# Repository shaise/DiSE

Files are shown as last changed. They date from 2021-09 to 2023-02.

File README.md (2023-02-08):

# DiSE
A DIY speed editor to use with video editing sw such as Davinci Resolve and others  
  
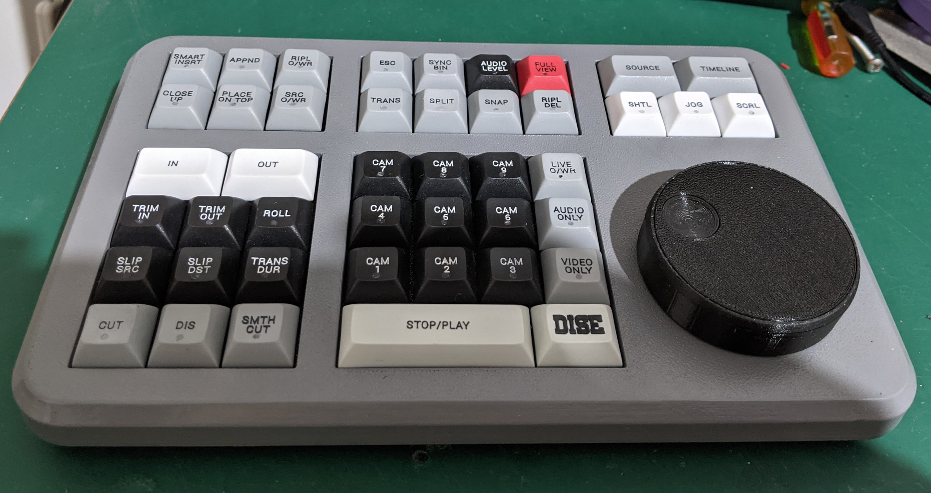
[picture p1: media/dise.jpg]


## Bill Of Materials:
- 1 [Bluepill Processor Board](#processor-module) 
- 1 [100ppr 5v Encoder](#encoder) 
- 44 [Cherry MX Keys and Sockets](#cherry-keys)
- 44 [Different sized Key Caps](#key-caps)
    -  DSA22 1u 18pc (18 x 1u)  
    -  DSA17 1u 18pc (18 x 1u)  
    -  DSA19 1u 4pc (4 x 1u)  
    -  DSA1 1u 3pc (3 x 1u)  
    -  DSA22 1.5u 2pc (4 x 1u)  
    -  DSA19 1.5u 2pc (4 x 1u)  
    -  DSA21 2u 2pc (4 x 1u)  
    -  DSA21 1.25u 1pc (2 x 1u)  
    -  DSA21 2.75u 1pc (3 x 1u)  
- 44 [3mm LEDs](#leds)  
- 1 [USB-C Connector](#usbc-connector)
- 18 [0603 Resistors (2x1k, 7x330R, 7x68R)](#resistors)
- 1 [small schottky diode](#diode)
- (Optional) [Encoder Connector](#connector)
- Access to a 3d Printer to print the case and knob under the mechanics folder.

### Processor Module:
Beware there are out there many STM32103 Clones under the blue pill name. Some Clones may not perform as the original STM32 processor. [More info](https://hackaday.com/2020/10/22/stm32-clones-the-good-the-bad-and-the-ugly/).
Definitely STM Software Utillities try hard to identify their own branded original chipsets and wont work on any other detectable clone. Wich makes debugging and developping very difficult.

#### **Recommended** 
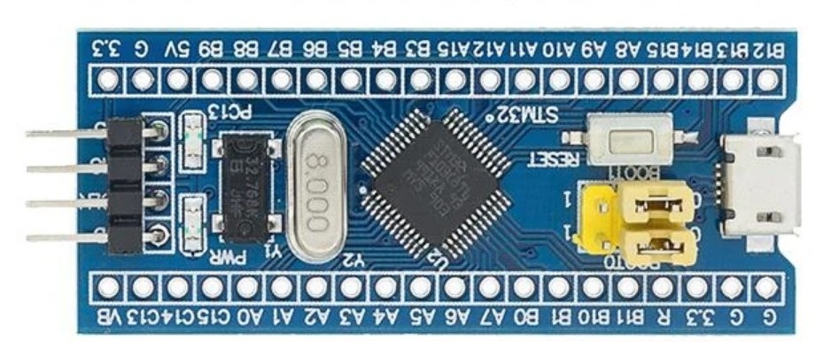
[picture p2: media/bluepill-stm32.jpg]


Blue-Pill with original STM32 Processor module: https://www.aliexpress.com/item/1766455290.html 
(order both STM32F103C8T6 and ST-Link V2 programmer)

#### **Cheaper Alternative** 
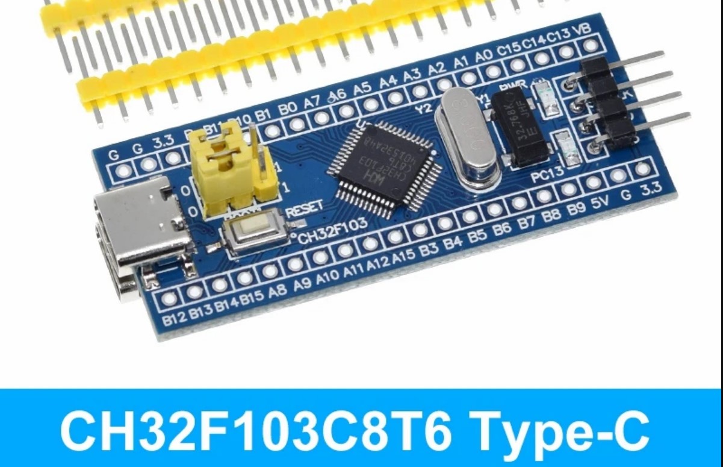
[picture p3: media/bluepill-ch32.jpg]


Blue-Pill with CH32F103C8T6 and two usb Ports. No need of ST-Link programmer. One USB-C port is used to download/upgrade the firmware using wch programming software. Can also be programmed with an ST-Link dongle and the old ST-Link004 from STM.
(Proved to work, cheaper, not compatible with newer STM Tools thought, only 64k, so not recomended for developping )

### Encoder
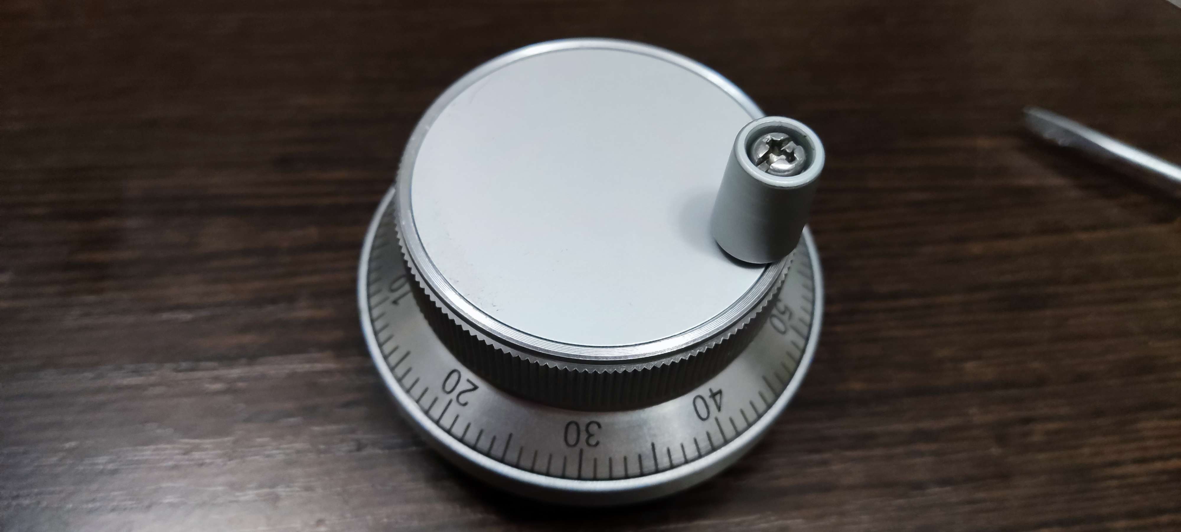
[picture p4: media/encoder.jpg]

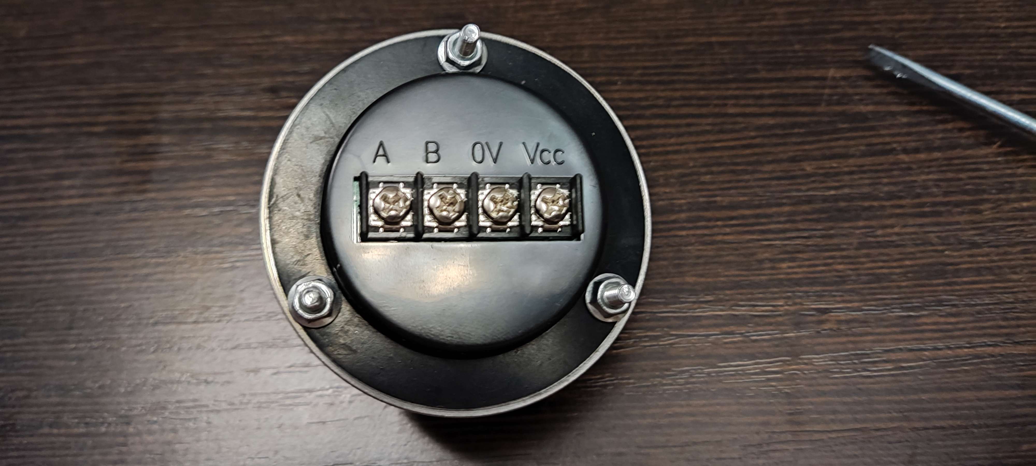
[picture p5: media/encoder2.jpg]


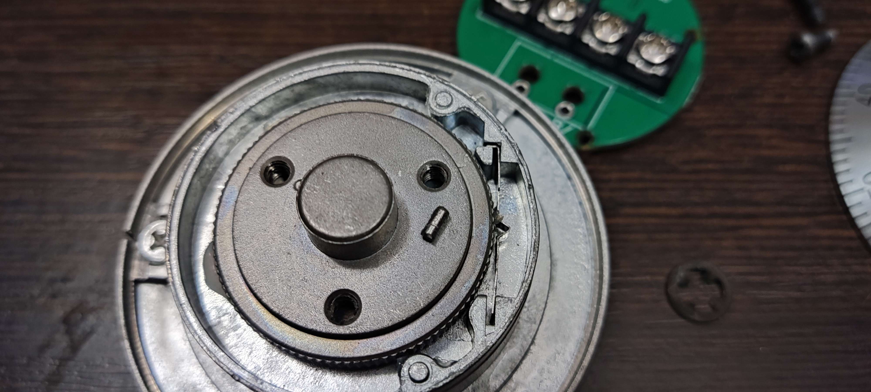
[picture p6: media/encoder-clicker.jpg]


**Optical Encoder 100ppr 5v 4pin 60mm** 
We will be modifying the top part to remove the bearing pin that acts as a clicker to let it run quieter and smoothly. 
The pin can be reached by removing the spindle handler screw, then remove the upper plate that it is glued to uncover the three screws that holds the knob in place, and after removing it dissasemble the support plate that holds the spring in place.
The pin can be taken from its place and saved safely for any future reassembly in the little space behind the spring.

Encoder: https://www.aliexpress.com/item/4000897699294.html 1 unit  

### Cherry Keys
Cherry MX Keys and Sockets

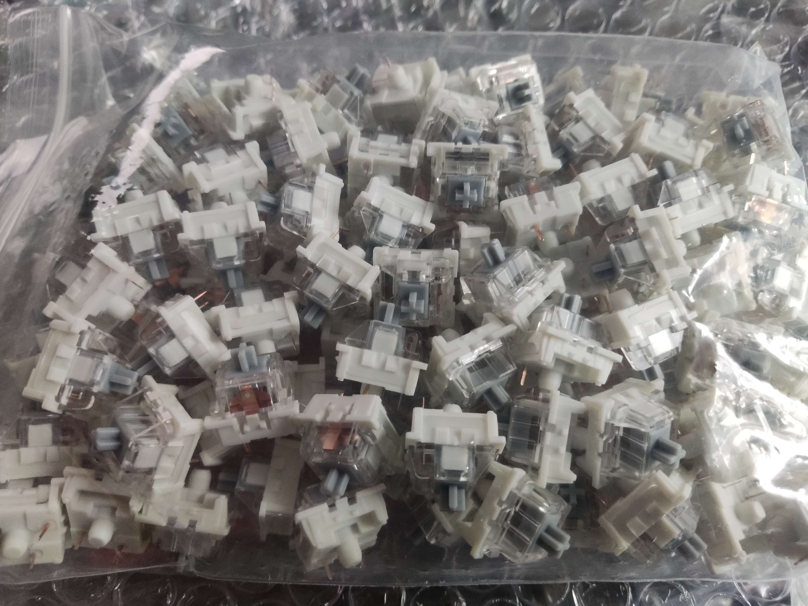
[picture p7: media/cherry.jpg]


Keys: https://www.aliexpress.com/item/1005002378701948.html Order Silent Gray type 44pcs (order 2 packs of 30)  

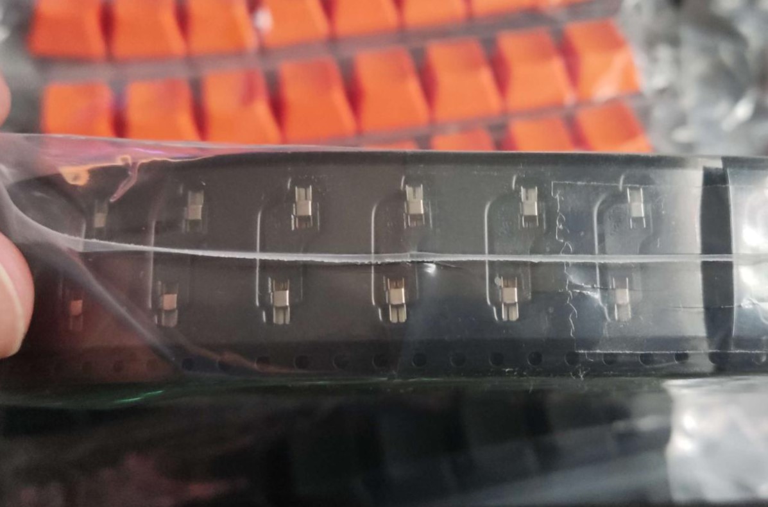
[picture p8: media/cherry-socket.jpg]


Key Sockets: https://www.aliexpress.com/item/4001051840976.html 44pcs (order 50 pcs ) 

### Key Caps
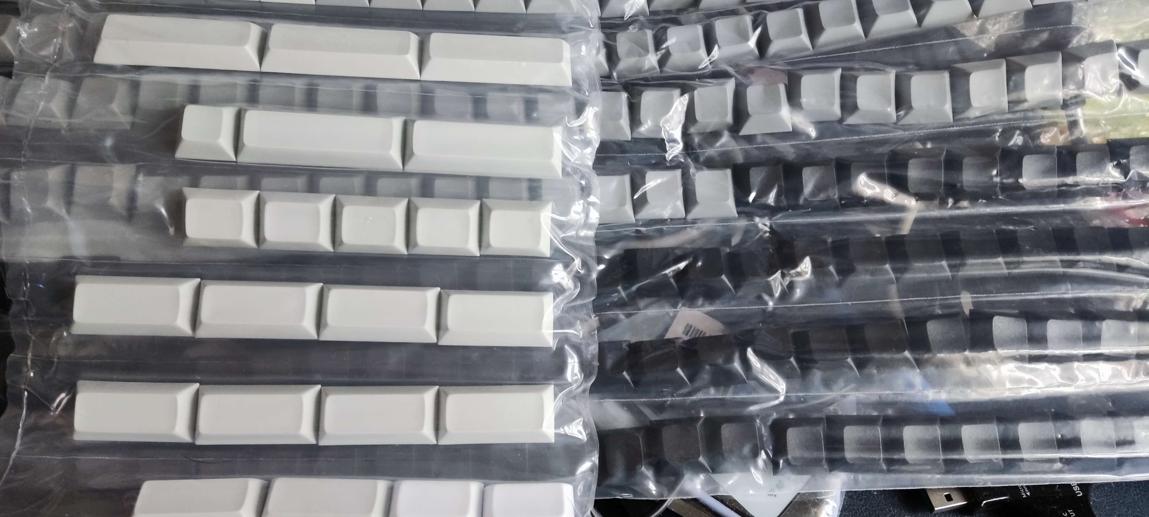
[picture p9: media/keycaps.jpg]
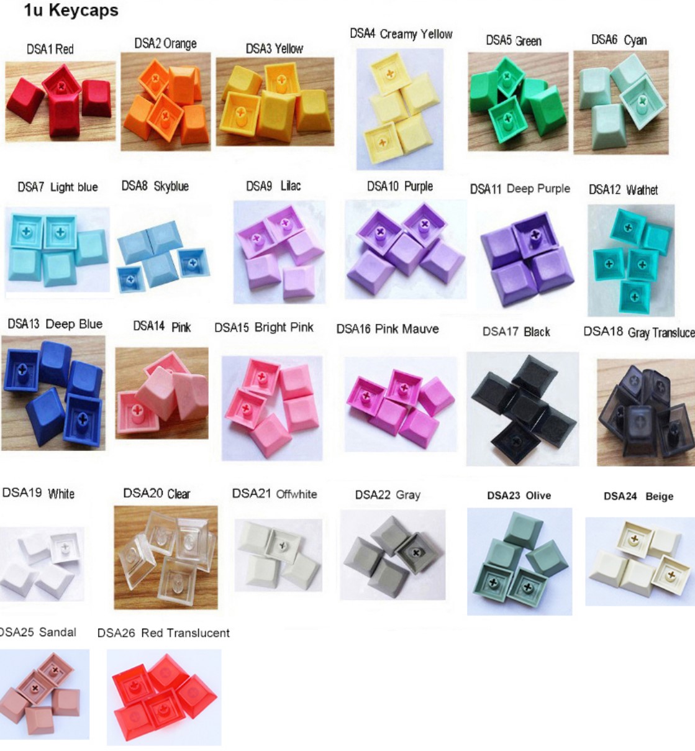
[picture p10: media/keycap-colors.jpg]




Key Caps: https://www.aliexpress.com/item/32850729893.html 44pcs (Order 60 pcs, and send the list below):  
-  DSA22 1u 18pc (18 x 1u)  (Gray)
-  DSA17 1u 18pc (18 x 1u)  (Black)
-  DSA19 1u 4pc (4 x 1u)    (White)
-  DSA1 1u 3pc (3 x 1u)     (Red)
-  DSA22 1.5u 2pc (4 x 1u)  (Gray)
-  DSA19 1.5u 2pc (4 x 1u)  (White)
-  DSA21 2u 2pc (4 x 1u)    (OffWhite)
-  DSA21 1.25u 1pc (2 x 1u) (OffWhite)
-  DSA21 2.75u 1pc (3 x 1u) (OffWhite)

This list will match the colors shown on the example picture showed above. 
Printing the layout text on the keycaps can be done using thermal sublimation ink, or laser printed.

**Beware** that if you don't have access to a printer with white thermal sublimation ink printing on the black keycaps (DSA17) can be challenging. You may want to change those to another color from the upper color table so you can transfer your layout text using common black toner for laser printers, or dark transfer ink.

Those samples were printed using whiteboard markers and a L1 laserpecker:

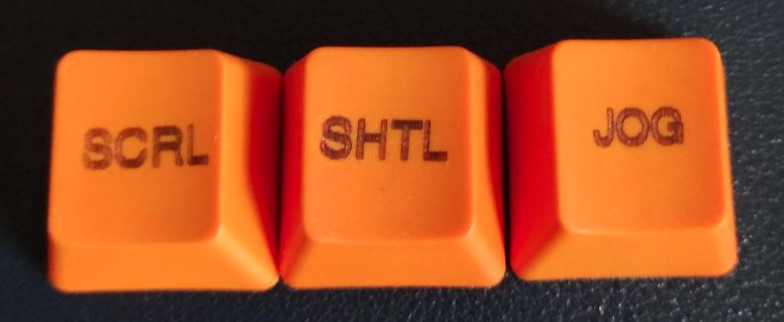
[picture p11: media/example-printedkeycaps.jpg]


This sample was lasered with a laserpecker and then filled the gap with paint. (extremely difficult to get it right)

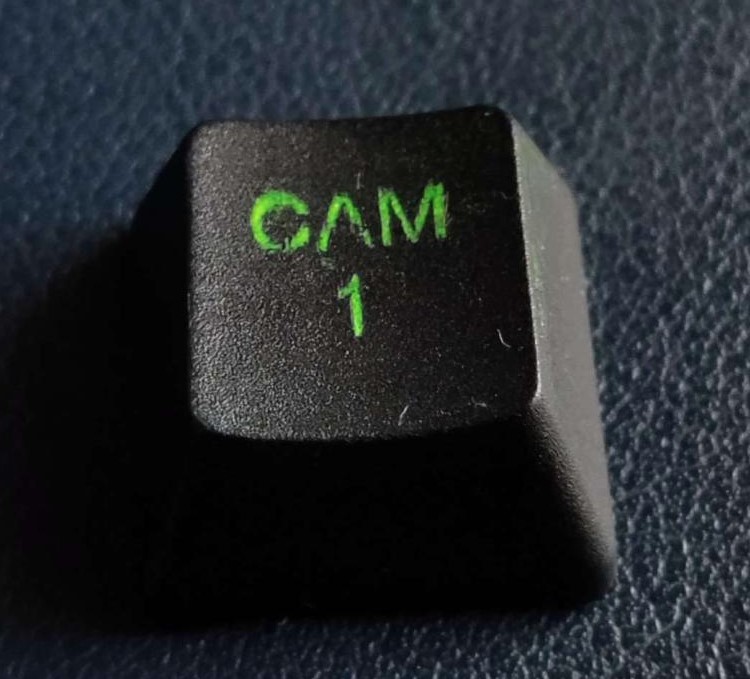
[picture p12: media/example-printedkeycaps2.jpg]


Check the assembly instructions to know more about how to DIY the keycap printing.

### LEDs 
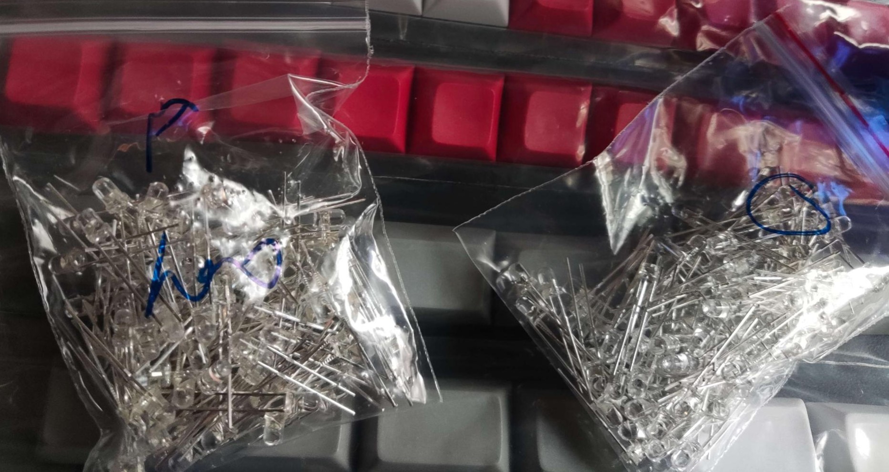
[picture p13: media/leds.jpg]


Standard 3mm LEDs. Any color. 
https://www.aliexpress.com/item/32685518028.html or any 3mm led, any color  44pcs

### USBC Connector
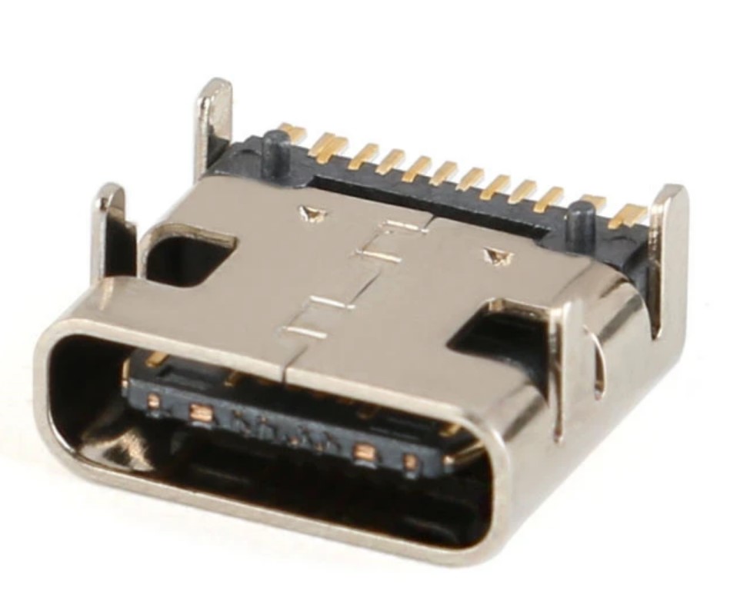
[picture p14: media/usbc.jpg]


If you chose the path of using the CH32 board, there is already a working connector you can use. Should that be the case, usbc cable can be plugged from right side. This breaked out connector is to move that to the center top.
If you chose the bluepill with only one usb connector (micro USB) there is no way around soldering this connector.

USB C connector: https://www.aliexpress.com/item/32976750426.html  

### Resistors 
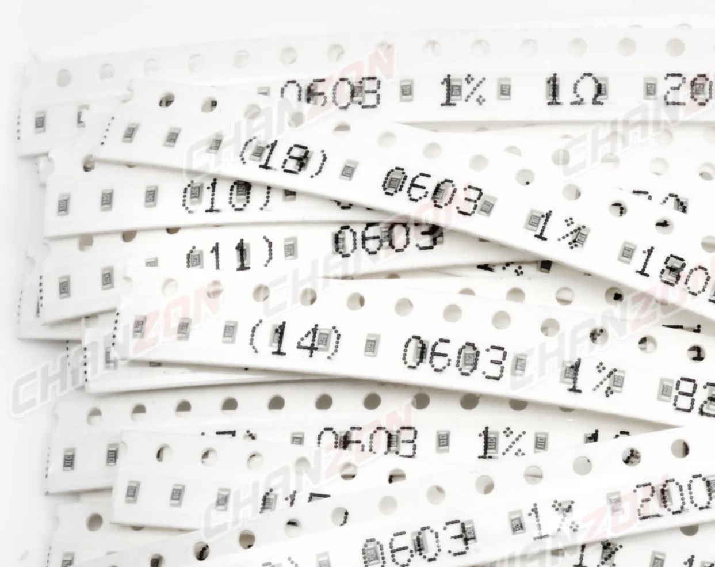
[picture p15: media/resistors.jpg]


0603 resistor kit: https://www.aliexpress.com/item/1005002364437129.html . Usage:
- R1 - R7 : 330 ohm (7pcs)
- R10 - R11 : 22 ohm (2pcs)
- R8 - R9 : 1K ohm (2pcs)
- R43 - R51: 68 ohm (7pcs)

If you struggle to find a kit that has the 68ohm value, 62ohm will work as well.

### Diode
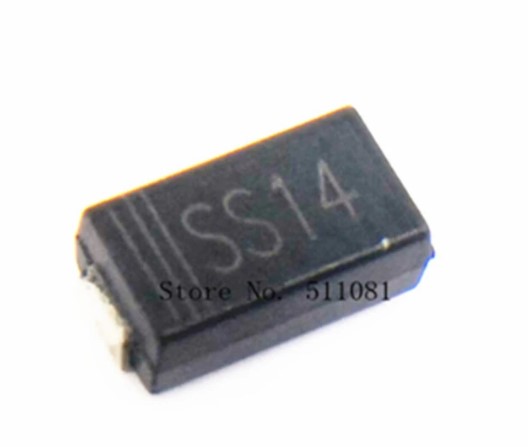
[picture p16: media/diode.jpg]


A small schottky diode. A 1N5819 SS14 SMD will work. 
1pc Needed, But its cheaper to get 100 than only one. https://www.aliexpress.com/item/627622453.html

### Connector
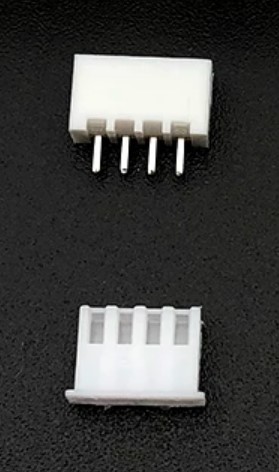
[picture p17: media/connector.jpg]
 

Optional 4pin pcb connector for the encoder. You may just skip this and solder the wires direct to the pcb

https://www.aliexpress.com/item/4000126563819.html

### Instructions 
TBD

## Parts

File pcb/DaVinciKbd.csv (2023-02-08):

Source: | C:\Users\carlo\Documents\GitHub\DiSE\pcb\DaVinciKbd.kicad_sch
Date: | 04/02/2023 15:40:26
Tool: | Eeschema (6.0.7)
Generator: | C:\Program Files\KiCad\6.0\bin\scripting\plugins/bom_csv_grouped_by_value.py
Component Count: | 79
Individual Components:
Item | Qty | Reference(s) | Value | LibPart | Footprint | Datasheet
 |  | D1 | 1N5819 | Device:D_Schottky_Small | Diode_SMD:D_SMA | ~
 |  | H1 | 3.6 MountingHole | Mechanical:MountingHole | BP:MountHole3.6 | ~
 |  | H2 | 3.6 MountingHole | Mechanical:MountingHole | BP:MountHole3.6 | ~
 |  | H3 | 3.6 MountingHole | Mechanical:MountingHole | BP:MountHole3.6 | ~
 |  | H4 | 3.6 MountingHole | Mechanical:MountingHole | BP:MountHole3.6 | ~
 |  | H5 | 3.6 MountingHole | Mechanical:MountingHole | BP:MountHole3.6 | ~
 |  | H6 | 3.6 MountingHole | Mechanical:MountingHole | BP:MountHole3.6 | ~
 |  | H7 | 3.6 MountingHole | Mechanical:MountingHole | BP:MountHole3.6 | ~
 |  | H8 | 3.6 MountingHole | Mechanical:MountingHole | BP:MountHole3.6 | ~
 |  | H9 | 3.6 MountingHole | Mechanical:MountingHole | BP:MountHole3.6 | ~
 |  | H10 | 3.6 MountingHole | Mechanical:MountingHole | BP:MountHole3.6 | ~
 |  | H11 | 3.6 MountingHole | Mechanical:MountingHole | BP:MountHole3.6 | ~
 |  | H13 | 3.6 MountingHole | Mechanical:MountingHole | BP:MountHole3.6 | ~
 |  | H14 | 3.6 MountingHole | Mechanical:MountingHole | BP:MountHole3.6 | ~
 |  | J1 | Conn_01x04 | Connector_Generic:Conn_01x04 | Connector_PinHeader_2.54mm:PinHeader_1x04_P2.54mm_Vertical | ~
 |  | J2 | USB_C_Receptacle_USB2.0 | DaVinciKbd-rescue:USB_C_Receptacle_USB2.0-Connector | BP:USB_C_Receptacle_Palconn_UTC16-G | https://www.usb.org/sites/default/files/documents/usb_type-c.zip
 |  | R1 | 330 | Device:R_Small | Resistor_SMD:R_0603_1608Metric | ~
 |  | R2 | 330 | Device:R_Small | Resistor_SMD:R_0603_1608Metric | ~
 |  | R3 | 330 | Device:R_Small | Resistor_SMD:R_0603_1608Metric | ~
 |  | R4 | 330 | Device:R_Small | Resistor_SMD:R_0603_1608Metric | ~
 |  | R5 | 330 | Device:R_Small | Resistor_SMD:R_0603_1608Metric | ~
 |  | R6 | 330 | Device:R_Small | Resistor_SMD:R_0603_1608Metric | ~
 |  | R7 | 330 | Device:R_Small | Resistor_SMD:R_0603_1608Metric | ~
 |  | R8 | 1K | Device:R_Small | Resistor_SMD:R_0603_1608Metric | ~
 |  | R9 | 1K | Device:R_Small | Resistor_SMD:R_0603_1608Metric | ~
 |  | R10 | 22 | Device:R_Small | Resistor_SMD:R_0603_1608Metric | ~
 |  | R11 | 22 | Device:R_Small | Resistor_SMD:R_0603_1608Metric | ~
 |  | R43 | 68 | Device:R_Small | Resistor_SMD:R_0603_1608Metric | ~
 |  | R46 | 68 | Device:R_Small | Resistor_SMD:R_0603_1608Metric | ~
 |  | R47 | 68 | Device:R_Small | Resistor_SMD:R_0603_1608Metric | ~
 |  | R48 | 68 | Device:R_Small | Resistor_SMD:R_0603_1608Metric | ~
 |  | R49 | 68 | Device:R_Small | Resistor_SMD:R_0603_1608Metric | ~
 |  | R50 | 68 | Device:R_Small | Resistor_SMD:R_0603_1608Metric | ~
 |  | R51 | 68 | Device:R_Small | Resistor_SMD:R_0603_1608Metric | ~
 |  | U1 | CherryMX_LED | CherryMX:CherryMX_LED | CherryMX_KailhSocket_LED:CherryMX_1.00u_KailhSocket_LED
 |  | U2 | CherryMX_LED | CherryMX:CherryMX_LED | CherryMX_KailhSocket_LED:CherryMX_1.00u_KailhSocket_LED
 |  | U3 | CherryMX15_LED | CherryMX:CherryMX_LED | CherryMX_KailhSocket_LED:CherryMX_1.50u_KailhSocket_LED
 |  | U4 | CherryMX_LED | CherryMX:CherryMX_LED | CherryMX_KailhSocket_LED:CherryMX_1.00u_KailhSocket_LED
 |  | U5 | CherryMX_LED | CherryMX:CherryMX_LED | CherryMX_KailhSocket_LED:CherryMX_1.00u_KailhSocket_LED
 |  | U6 | CherryMX_LED | CherryMX:CherryMX_LED | CherryMX_KailhSocket_LED:CherryMX_1.00u_KailhSocket_LED
 |  | U7 | CherryMX_LED | CherryMX:CherryMX_LED | CherryMX_KailhSocket_LED:CherryMX_1.00u_KailhSocket_LED
 |  | U8 | CherryMX_LED | CherryMX:CherryMX_LED | CherryMX_KailhSocket_LED:CherryMX_1.00u_KailhSocket_LED
 |  | U9 | CherryMX_LED | CherryMX:CherryMX_LED | CherryMX_KailhSocket_LED:CherryMX_1.00u_KailhSocket_LED
 |  | U10 | CherryMX_LED | CherryMX:CherryMX_LED | CherryMX_KailhSocket_LED:CherryMX_1.00u_KailhSocket_LED
 |  | U11 | CherryMX_LED | CherryMX:CherryMX_LED | CherryMX_KailhSocket_LED:CherryMX_1.00u_KailhSocket_LED
 |  | U12 | CherryMX_LED | CherryMX:CherryMX_LED | CherryMX_KailhSocket_LED:CherryMX_1.00u_KailhSocket_LED
 |  | U13 | CherryMX_LED | CherryMX:CherryMX_LED | CherryMX_KailhSocket_LED:CherryMX_1.00u_KailhSocket_LED
 |  | U14 | CherryMX15_LED | CherryMX:CherryMX_LED | CherryMX_KailhSocket_LED:CherryMX_1.50u_KailhSocket_LED
 |  | U15 | CherryMX_LED | CherryMX:CherryMX_LED | CherryMX_KailhSocket_LED:CherryMX_1.00u_KailhSocket_LED
 |  | U16 | CherryMX_LED | CherryMX:CherryMX_LED | CherryMX_KailhSocket_LED:CherryMX_1.00u_KailhSocket_LED
 |  | U17 | CherryMX_LED | CherryMX:CherryMX_LED | CherryMX_KailhSocket_LED:CherryMX_1.00u_KailhSocket_LED
 |  | U18 | CherryMX_LED | CherryMX:CherryMX_LED | CherryMX_KailhSocket_LED:CherryMX_1.00u_KailhSocket_LED
 |  | U19 | CherryMX_LED | CherryMX:CherryMX_LED | CherryMX_KailhSocket_LED:CherryMX_1.00u_KailhSocket_LED
 |  | U20 | CherryMX_LED | CherryMX:CherryMX_LED | CherryMX_KailhSocket_LED:CherryMX_1.00u_KailhSocket_LED
 |  | U21 | CherryMX_LED | CherryMX:CherryMX_LED | CherryMX_KailhSocket_LED:CherryMX_1.00u_KailhSocket_LED
 |  | U22 | CherryMX_LED | CherryMX:CherryMX_LED | CherryMX_KailhSocket_LED:CherryMX_1.00u_KailhSocket_LED
 |  | U23 | CherryMX275_LED | CherryMX:CherryMX_LED | CherryMX_KailhSocket_LED:CherryMX_2.75u_KailhSocket_LED
 |  | U24 | CherryMX_LED | CherryMX:CherryMX_LED | CherryMX_KailhSocket_LED:CherryMX_1.00u_KailhSocket_LED
 |  | U25 | CherryMX_LED | CherryMX:CherryMX_LED | CherryMX_KailhSocket_LED:CherryMX_1.00u_KailhSocket_LED
 |  | U26 | CherryMX_LED | CherryMX:CherryMX_LED | CherryMX_KailhSocket_LED:CherryMX_1.00u_KailhSocket_LED
 |  | U27 | CherryMX_LED | CherryMX:CherryMX_LED | CherryMX_KailhSocket_LED:CherryMX_1.00u_KailhSocket_LED
 |  | U28 | CherryMX_LED | CherryMX:CherryMX_LED | CherryMX_KailhSocket_LED:CherryMX_1.00u_KailhSocket_LED
 |  | U29 | CherryMX_LED | CherryMX:CherryMX_LED | CherryMX_KailhSocket_LED:CherryMX_1.00u_KailhSocket_LED
 |  | U30 | CherryMX_LED | CherryMX:CherryMX_LED | CherryMX_KailhSocket_LED:CherryMX_1.00u_KailhSocket_LED
 |  | U31 | CherryMX_LED | CherryMX:CherryMX_LED | CherryMX_KailhSocket_LED:CherryMX_1.00u_KailhSocket_LED
 |  | U32 | CherryMX_LED | CherryMX:CherryMX_LED | CherryMX_KailhSocket_LED:CherryMX_1.00u_KailhSocket_LED
 |  | U33 | CherryMX_LED | CherryMX:CherryMX_LED | CherryMX_KailhSocket_LED:CherryMX_1.00u_KailhSocket_LED
 |  | U34 | CherryMX_LED | CherryMX:CherryMX_LED | CherryMX_KailhSocket_LED:CherryMX_1.00u_KailhSocket_LED
 |  | U35 | CherryMX_LED | CherryMX:CherryMX_LED | CherryMX_KailhSocket_LED:CherryMX_1.00u_KailhSocket_LED
 |  | U36 | CherryMX_LED | CherryMX:CherryMX_LED | CherryMX_KailhSocket_LED:CherryMX_1.00u_KailhSocket_LED
 |  | U37 | CherryMX_LED | CherryMX:CherryMX_LED | CherryMX_KailhSocket_LED:CherryMX_1.00u_KailhSocket_LED
 |  | U38 | CherryMX_LED | CherryMX:CherryMX_LED | CherryMX_KailhSocket_LED:CherryMX_1.00u_KailhSocket_LED
 |  | U39 | CherryMX125_LED | CherryMX:CherryMX_LED | CherryMX_KailhSocket_LED:CherryMX_1.25u_KailhSocket_LED
 |  | U40 | CherryMX15_LED | CherryMX:CherryMX_LED | CherryMX_KailhSocket_LED:CherryMX_1.50u_KailhSocket_LED
 |  | U41 | CherryMX_LED | CherryMX:CherryMX_LED | CherryMX_KailhSocket_LED:CherryMX_1.00u_KailhSocket_LED
 |  | U42 | CherryMX_LED | CherryMX:CherryMX_LED | CherryMX_KailhSocket_LED:CherryMX_1.00u_KailhSocket_LED
 |  | U43 | BP | bluepill:BP | BP:BLUEPILL-BARE
 |  | U44 | CherryMX15_LED | CherryMX:CherryMX_LED | CherryMX_KailhSocket_LED:CherryMX_1.50u_KailhSocket_LED
 |  | U45 | CherryMX_LED | CherryMX:CherryMX_LED | CherryMX_KailhSocket_LED:CherryMX_1.00u_KailhSocket_LED
Collated Components:
Item | Qty | Reference(s) | Value | LibPart | Footprint | Datasheet
1 | 1 | D1 | 1N5819 | Device:D_Schottky_Small | Diode_SMD:D_SMA | ~
2 | 13 | H1, H2, H3, H4, H5, H6, H7, H8, H9, H10, H11, H13, H14 | 3.6 MountingHole | Mechanical:MountingHole | BP:MountHole3.6 | ~
3 | 1 | J1 | Conn_01x04 | Connector_Generic:Conn_01x04 | Connector_PinHeader_2.54mm:PinHeader_1x04_P2.54mm_Vertical | ~
4 | 1 | J2 | USB_C_Receptacle_USB2.0 | DaVinciKbd-rescue:USB_C_Receptacle_USB2.0-Connector | BP:USB_C_Receptacle_Palconn_UTC16-G | https://www.usb.org/sites/default/files/documents/usb_type-c.zip
5 | 7 | R1, R2, R3, R4, R5, R6, R7 | 330 | Device:R_Small | Resistor_SMD:R_0603_1608Metric | ~
6 | 2 | R8, R9 | 1K | Device:R_Small | Resistor_SMD:R_0603_1608Metric | ~
7 | 2 | R10, R11 | 22 | Device:R_Small | Resistor_SMD:R_0603_1608Metric | ~
8 | 7 | R43, R46, R47, R48, R49, R50, R51 | 68 | Device:R_Small | Resistor_SMD:R_0603_1608Metric | ~
9 | 38 | U1, U2, U4, U5, U6, U7, U8, U9, U10, U11, U12, U13, U15, U16, U17, U18, U19, U20, U21, U22, U24, U25, U26, U27, U28, U29, U30, U31, U32, U33, U34, U35, U36, U37, U38, U41, U42, U45 | CherryMX_LED | CherryMX:CherryMX_LED | CherryMX_KailhSocket_LED:CherryMX_1.00u_KailhSocket_LED
10 | 4 | U3, U14, U40, U44 | CherryMX15_LED | CherryMX:CherryMX_LED | CherryMX_KailhSocket_LED:CherryMX_1.50u_KailhSocket_LED
11 | 1 | U23 | CherryMX275_LED | CherryMX:CherryMX_LED | CherryMX_KailhSocket_LED:CherryMX_2.75u_KailhSocket_LED
12 | 1 | U39 | CherryMX125_LED | CherryMX:CherryMX_LED | CherryMX_KailhSocket_LED:CherryMX_1.25u_KailhSocket_LED
13 | 1 | U43 | BP | bluepill:BP | BP:BLUEPILL-BARE

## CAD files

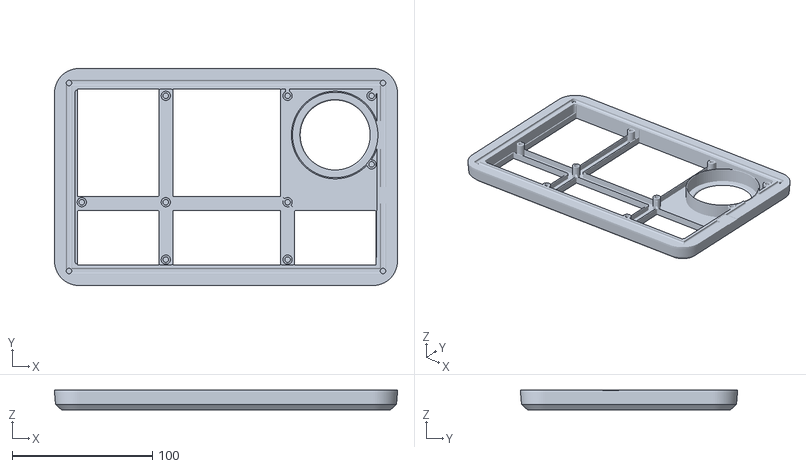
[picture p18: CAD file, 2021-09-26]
mechanics/3d_print/DavinciKbdTop.stl
245.0 x 155.0 x 14.1

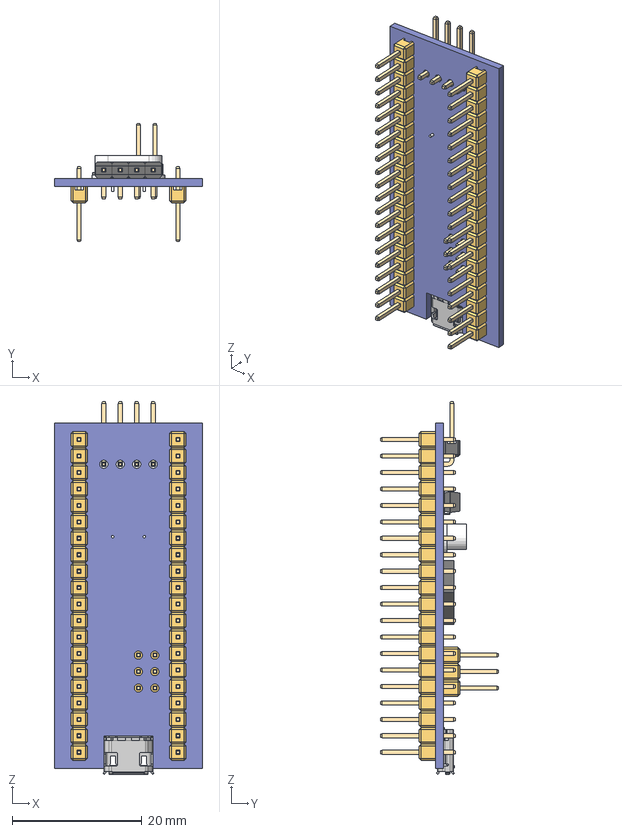
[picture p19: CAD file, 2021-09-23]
pcb/models/STM32F103C8T6_Blue_Pill v6.step
22.9 x 18.3 x 57.6 mm
Oscillator_HC-49/S
STM32F103C8T6_BluePill_Board
Oscillator_MC-306
STM32_LQFP48
Tactile_SMD_5x5mm
Header_L4_10x4.8
Header_Male_2x3x11.6
Header_Male_1x20x11.6 x 2

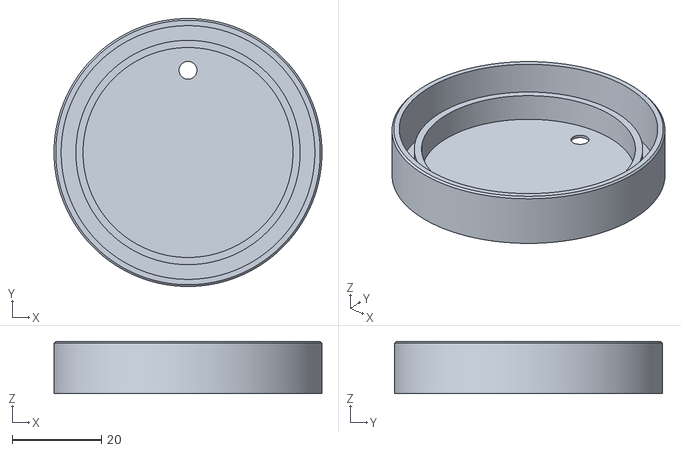
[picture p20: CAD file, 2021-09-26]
mechanics/3d_print/KbdEncoderBase.stl
60.0 x 60.0 x 11.7

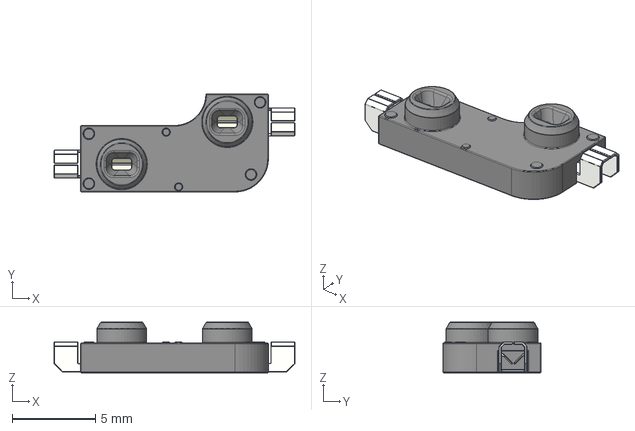
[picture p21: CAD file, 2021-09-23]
pcb/models/KailhSocket.stp
14.5 x 5.89 x 3.05 mm

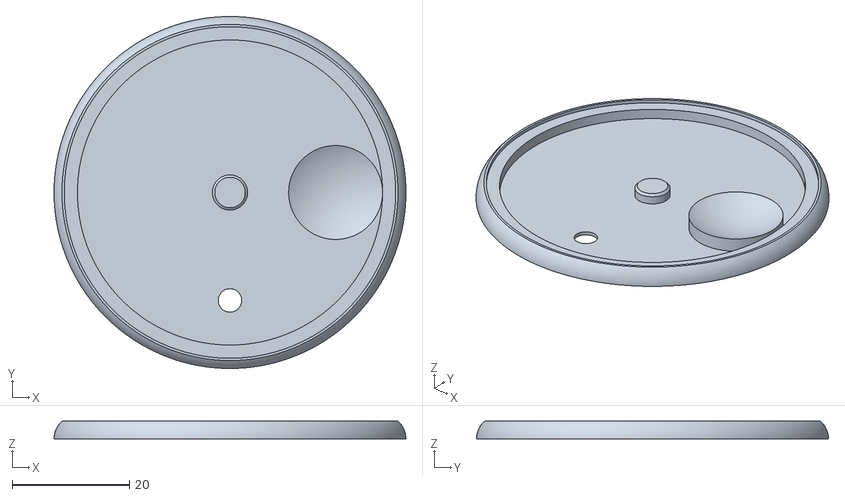
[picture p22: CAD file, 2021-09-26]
mechanics/3d_print/KbdEncoderTop.stl
60.0 x 60.0 x 3.00

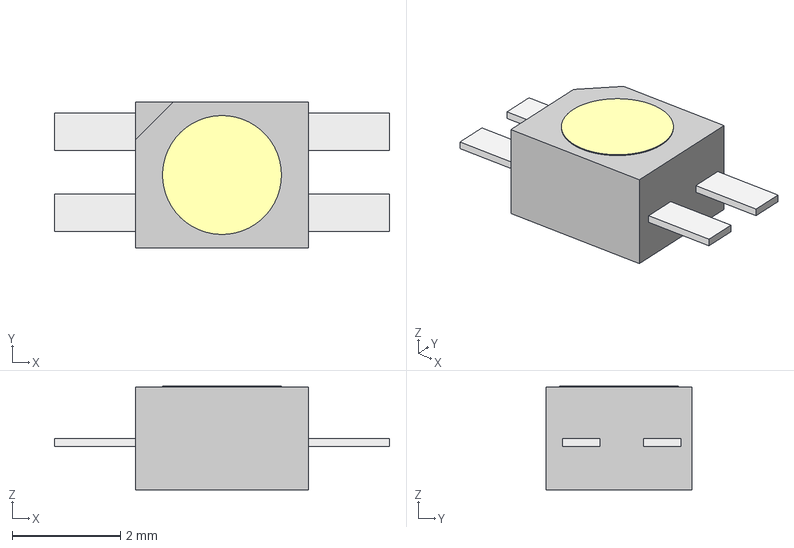
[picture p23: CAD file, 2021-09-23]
pcb/models/LTST-A683CEGBW.step
6.20 x 2.70 x 1.92 mm

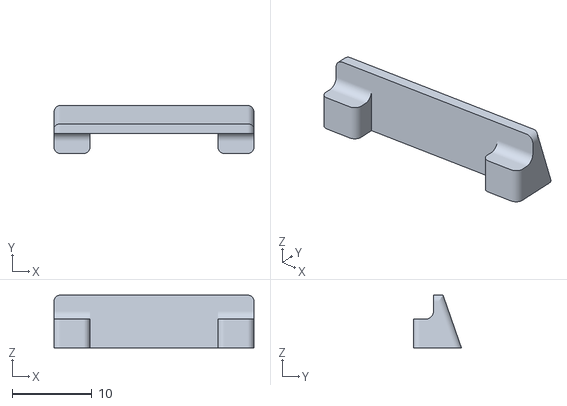
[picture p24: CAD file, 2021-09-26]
mechanics/3d_print/WireHolder2.stl
25.0 x 6.00 x 6.60

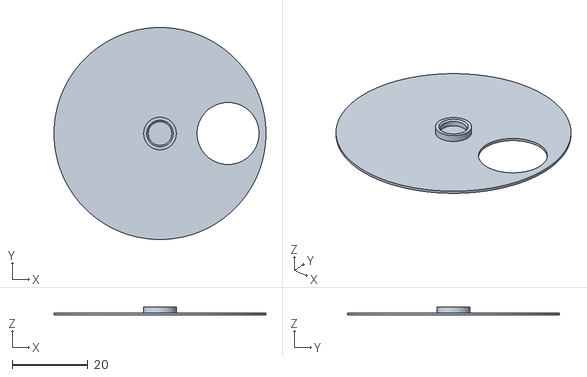
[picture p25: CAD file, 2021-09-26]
mechanics/3d_print/KbdEncoderCap.stl
56.1 x 56.1 x 2.20

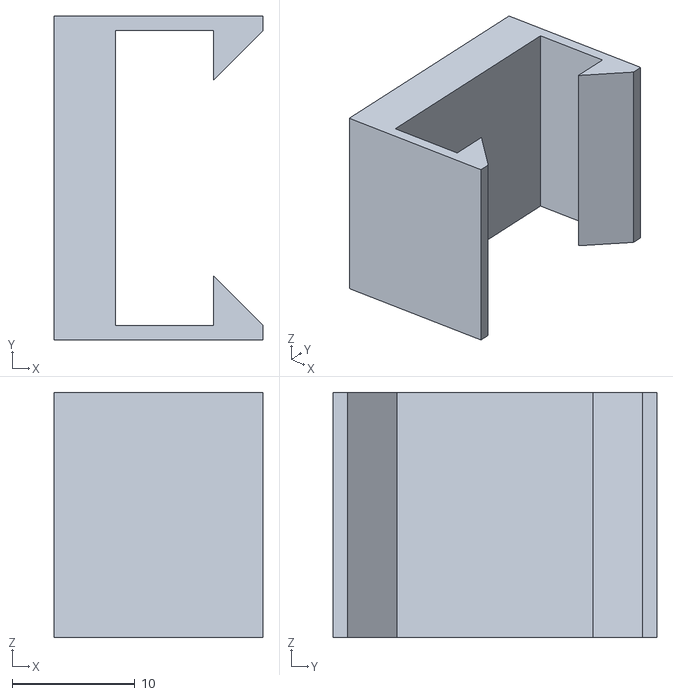
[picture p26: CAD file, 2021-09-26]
mechanics/3d_print/KeyCapHolder.stl
17.0 x 26.4 x 20.0

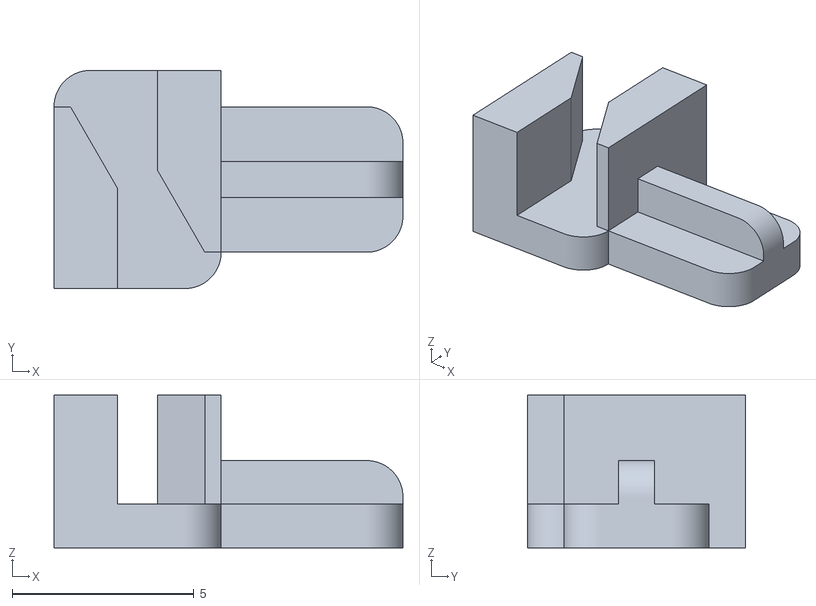
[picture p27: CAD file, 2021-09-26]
mechanics/3d_print/KeyCapPin2.stl
9.60 x 6.00 x 4.20

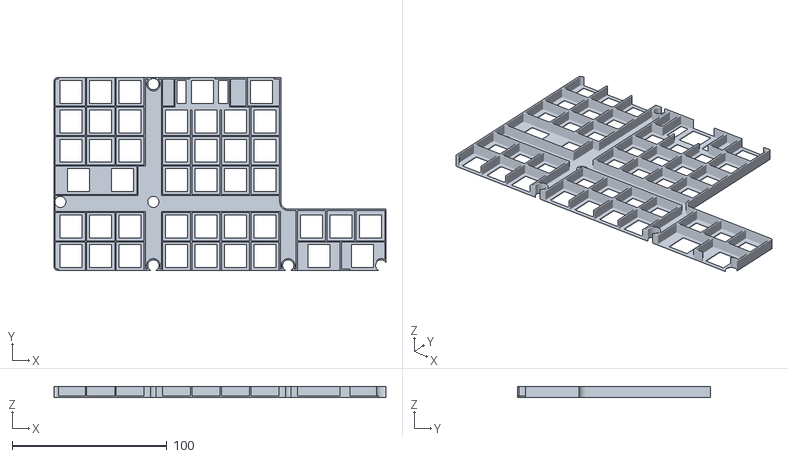
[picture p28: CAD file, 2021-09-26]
mechanics/3d_print/KeyRestrainer.stl
214.2 x 124.2 x 6.80

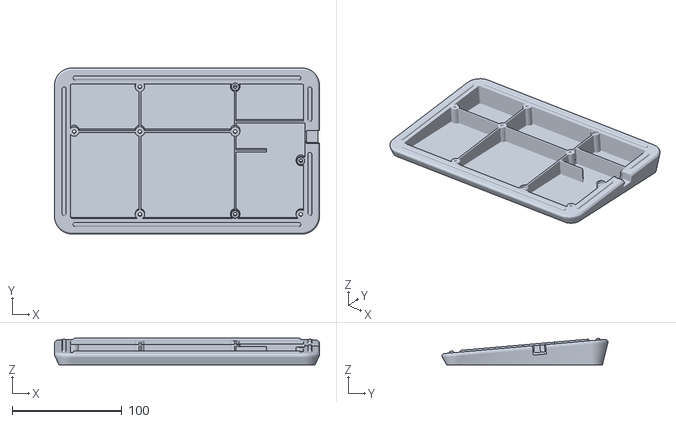
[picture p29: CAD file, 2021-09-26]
mechanics/3d_print/DaVinciKbdBot.stl
242.0 x 151.6 x 24.2

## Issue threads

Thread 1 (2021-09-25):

How to use

Bijileshkb, 2021-09-25:
How to use Davinci Resolve speed editor to use with video editing SW such as Final Cut Pro and others?

shaise, 2021-09-25:
You can not use Davinci Resolve's original speed editor on any sw other then Davinci's. But the one I'm working on can be used on any sw since it is programmable. Instructions and video on the way.

Bijileshkb, 2021-09-26:
First up, thank you for developing for us. Actually, I'm looking forward to
seeing this kind of software. Now I,m a user mac OS Big Sur, How to my
Davinci Resolve speed Editor use on any SW?
Please do it for us.

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

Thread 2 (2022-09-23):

A year passed by

CJGuirao, 2022-09-23:
Hello,
I found this project and I would really like to replicate it.

Could you help me out answering some questions?

It ended up working with davinci?
Is there a recommended BOM?
Wich encoder did you use? It is the most important part for usability.

Did you DIY yourself the keycaps? do you reccommend where to get them?

I'd like to replicate the project, and once it is working modify the software so it could be used aswell with other software like OBS Studio. to provide more flexibility.

Thank you very much in advance.

shaise, 2022-09-24:
Hi Carlos!

Sorry, Sorry, for not adding all the docs and instructions as I planned to. I have a lot of video footage to edit and publish but did not find time to do it.
Anyway, I have added all the missing info for you in the main Readme.MD section.
Also added a release version with PCB manufacture files, compiled firmware, and PC configuration SW.

To your questions:
1. Yes, it works with DaVinci, but I did not implement all possible functions.
2. Bom is now in the readme + links where to buy.
3. The encoder also have a link in the readme. When you ged it you should make a small modification: Open the cap, and lossen the spring that make the encoder click when rotating. This will give you much smoother operation.
4. Yes I made the key caps myself. I ordered blank caps (again, links in the readme), then uses Toner powder + laser engraver to write the text. See this video: https://www.youtube.com/watch?v=JR1BwcFyexQ
5. No need to modify the software! the PC App (in the release files) lets you connect to the keyboard and customize it to any software you want to use it for.

Feel free to contact me with any questions.

CJGuirao, 2022-09-26:
Thank you very much for all the information.
I've already ordered a few PCBs and I'm looking forward to try to asemble it.

I'll keep you uptaded :)
Let's see how it goes

CJGuirao, 2022-10-19:
Update:
PCBs arrived, waiting for the rest of the components.

Just found out that the product in wich this project was inspired uses a magnetic encoder using a variation of the well known as5600 that outputs A and B (quadrature output) the same way that this board needs.  (take a look of as5601).
Pretty difficult to get at a reasonable price. But I might explore that option if I can get one.

Again, thank you very much for your work, and for making this publicly avaliable.

CJGuirao, 2022-10-25:
I received the encoders, chose this seller (cheaper)
https://es.aliexpress.com/item/1005004437852504.html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
it is optical aswell, can be modified to remove the detent, and is metallic.

I'm gonna assemble one unit and check how good this encoder feels.

shaise, 2022-10-25:
this is exactly the one I used. good.

CJGuirao, 2022-10-25:
Fully dissasembled to check quality od the encoder part itself.
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
Where the detent pin is located to be removed (place  it behind the spring so you don't loseit in case you may want to have it back in its place in the future).
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
Feel free to use the images if you want to explain it in the readme for the future hackers

CJGuirao, 2023-01-31:
Progress update and some help needed:
We managed to solder everything but the LEDs.
I'd be nice for future people using this project to add polarity of the diodes, and LEDs in the silkscreen. And a table of Resistor values) I'll try to add it myself once everything is working and commit a pull request

We got it on video if anyone is interested. (Spanish audio tho)
https://www.twitch.tv/videos/1722772854 (Soldering job of the usbc connector and some resistors)
https://www.twitch.tv/videos/1723070128 (Soldering everything but the LED )

We didnt solder the leds because we tried and failed to load the program to the bue pill
(our intention was to test the progress so far, and be able to check empirically our assumption of LED polarity instead of soldering all 44 LEDs )

But we are having problems. because the bluepill doesn't identify itself as a device in windows.
We assumed the programming steps to be download the st-link utility and burn the bin in the 0x08000000 address
We tried burning it with boot0 in 0 and in 1 position.

No success so far.
It's my first time using this dev board, so any help to get it working would be appreciated.
Whats correct the procedure to program the board?
Whats the correct configuration of boot0 and boot1 while programming the board?
Whats the configuration of the two jumpers to boot as the device that the board is emulating?

As a side note it seems that bluepill is getting everywhere with false stm32 chips and we may have one of those. So we are asking for this instructions and details to differenciate between our own ineptitude or a maybe non working stm32 chinese clone.

CJGuirao, 2023-02-01:
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

CJGuirao, 2023-02-01:
### Nevermind ###
Got it working by modifying the source code.
In it it was assumed that most of the stm32 have 128k of memory instead of the advertised 64k.
It turns out that my probably counterfeit stm32 chinese clone board has 64k
Now its recognized so tomorrow we'll continue the assembly
[DavinciKbd4StupidChineseClones.zip](https://github.com/shaise/DiSE/files/10553542/DavinciKbd4StupidChineseClones.zip)

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

CJGuirao, 2023-02-01:
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
´

shaise, 2023-02-01:
Nice work!!
Yes, counterfeit stm32 are a big issue, since stm32 IDE usually detect them and will not let you program/debug the chip. If you work with arduino interface, it will not be an issue. also, you can compile with the ide then program with the ST-Link utility which works on the Chinese ones as well. But then of course, no debugging is possible.
I see also that you found a USB-C version of the BluePill. thats nice. My original board did not have the extra connector at the top, and I didn't like the usb-micro connector originally came with the blue-pill.

CJGuirao, 2023-02-01:
When you know what's the actual issue that is preventing it to work gets easier to solve.
As it always happens.

For those how are reading this with cheapo blue pills .

Use my .bin or:

Download stm32idecube and edit the project commenting out the line that sets the 128k memory size in the main file.

So now it will be suited for 64k boards

Then edit the build configuration to create the .bin file that you will use to upload the program.

Then upload it to the blue pill using the old st-link utility

 Or if your board has a ch32 chip you can set the boot0 to 1 and then program the thing using the bottom USBC port and the wch utility programmer.
The return the jumper to position 0 and your devices auld work on the top usbc and the break out USBC port at the top of the DISE board.
No need to use a st-link programmer in this case. Everything is done using the provided USBC ports.

shaise, 2023-02-01:
> Or if your board has a ch32 chip you can set the boot0 to 1 and then program the thing using the bottom USBC port and the wch utility programmer.
Interesting! I did not know that.

CJGuirao, 2023-02-02:
> > Or if your board has a ch32 chip you can set the boot0 to 1 and then program the thing using the bottom USBC port and the wch utility programmer.
>
> Interesting! I did not know that.

When boot0 is set to 1 the bottom USBC is recognized as a USB module that communicates with the wch programmer. It seems that they preprogrammed a bootloader there to be able to burn the chip without a dedicated dongle.

CJGuirao, 2023-02-02:
Today's progress and new weird problems.

We are done soldering all the LEDs and ready to test.

The device works as expected on every key except for the 21 key
That key doesn't work and in the DISE programmer does not light up when pressed.

Does not function as an ESC key and when reprogrammed to be a character A does not write it.

Every other key is recognized and works.

Even the keys on the same column and the same row.
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
shaise, 2023-02-07:
> **Schems**: I've characterized the resistors, and diode in the schema. Also written in the silkscreen a little table of the components And diode polarity as requested by YT @canaltornillo I'll commit a pull request soon.

Thanks! good idea!

> There is a strange bug that drove me crazy, and in this process, I'll try to fix. If you insert the keyboard on different USB ports, windows remembers all of them so there is "multiple keyboards but just one connected and active"

As far as I remember this should have been handled, but I will take another look.

CJGuirao, 2023-02-10:
> > There is a strange bug that drove me crazy, and in this process, I'll try to fix. If you insert the keyboard on different USB ports, windows remembers all of them so there is "multiple keyboards but just one connected and active"
>
> As far as I remember this should have been handled, but I will take another look.

I've opened a different thread to discuss about the problem and already found a temporary fix
https://github.com/shaise/DiSE/issues/4

CJGuirao, 2023-02-11:
Progress After having redrawn the case and a Visit to Youtube Channel @CanalTornillo I came back home with a new case made out of wood.
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

shaise, 2023-02-12:
Wow! Amazing.
Is it hand made or CNC made?

CJGuirao, 2023-02-13:
Tolerances of that thing are not possible to hand make.

There are 44 keys that should be done between .1 to .2 mm to be able to properly hold the keys.

It is CNCed thanks to the awesome help of @canaltornillo

I redesigned the case based on your current 3d printable work and taking all the measurements from the kicad project.

There is footage of it. That I'll expect soon to be released.

Maybe tomorrow I'll be available to try the final assembly and test on it.

If this design works,
Should anyone want to have one of those instead of printing their own I could relay their messages to canaltornillo. So they reach an agreement to produce one or more.

The hardest part. Creating the routes is already done. So making more it's easier now.

Doing it in wood may be a bit overkill... But I wanted to have something that feels special to me.

It took me about 3 days to design the case. With no previous experience in fusion 360.
Awesome program btw. New images and documentation for assembly soon...
 And it took us 1 day to create the actual tool paths in gcode and cut the wood.

This first prototype is not perfect. Next ones for himself and three other friends are going to be spotless.

shaise, 2023-02-13:
As a CNC user I'm totally impressed!
This is one heck of a complicated toolpath...
(I'm tempted to use yours to make one myself...)

> Next ones for himself and three other friends are going to be spotless.

Yes! Spread the word!
I have lots of video footage with the making processes. I was a bit lazy to edit it, perhaps it a good time to do it.

CJGuirao, 2023-02-13:
> (I'm tempted to use yours to make one myself...)

I'll commit the 2d dxf drawing to the mechanics folder once assembled and final.

We are 5 friends and I sourced the components to build five.

Pine wood is somewhat soft and weak. Something more dimensionanble stable would be great.

Pine was chosen just because of the pricing of nowadays wood planks

shaise, 2023-02-13:
Pine is indeed weak. I have some mahogany wood chunks just waiting for a nice project. With some shiny clear coating it should look great...

CJGuirao, 2023-02-15:
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

CJGuirao, 2023-02-15:
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

shaise, 2023-02-16:
Very nice indeed!

BaselineDesign, 2025-07-25:
just found this product and I'm really impressed. would you be able to take a moment to explain how you where able to replicate scrolling the playhead the same way the origial speed editor does? I cant find any shortcuts in davinci that let you scrub the playhead.

CJGuirao, 2025-07-26:
It's been a long time since I read the code but you can use arrow keys with or without modifier keys to jump at different speeds through the timeline.

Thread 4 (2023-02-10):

DISE Programmer application sometimes won't use the correct handle to access the HID Keyboard.

CJGuirao, 2023-02-10:
I separated this issue in a new different thread for the shake of clarity.

### Problem:
Sometimes after plugging and unplugging the keyboard in different ports the keyboard the Programmer app won't be able to communicate to the keyboard.

### Causes:
It seems that when you plug the DISE there are two devices listed as connected in windows HIDLibrary.
The last one is always used. But not always the correct one.

### How to replicate:
Connect the keyboard in different USB ports until the app stops showing any of the keypresses despite of showing the green connected icon.

### Workaround:
Disconnect the DISE and then using a program like devmanview remove all the non  connected HID entries. then connect the keyboard and it will work again. Beause windows will list the devices and install the drivers in the right order.

### Details and a temporary fix:
I've changed the code from the InitDevice to debug whats been listed, and all the available information from each device using this code:
** MainWindow.xml.cs** Line 248 function InitDevice()
`
 private void InitDevice()
        {
            if (kbdDevice != null)
                return;
            foreach (HidDevice detectedKbd in HidDevices.Enumerate(VendorId, ProductId)) {
                Console.WriteLine("Detected one Keyboard connected!");
                Console.WriteLine("Detected: " + detectedKbd.ToString());
                Console.WriteLine("Description: " + detectedKbd.Description.ToString());
                Console.WriteLine("DevicePath: " + detectedKbd.DevicePath.ToString());
                Console.WriteLine("Attributes: " + detectedKbd.Attributes.ToString());
                Console.WriteLine("Capabilites: " + detectedKbd.Capabilities.ToString());
                if (detectedKbd != null && detectedKbd.IsConnected &&  detectedKbd.DevicePath.Substring(detectedKbd.DevicePath.Length - 3) != "kbd")
                {
                    Console.WriteLine("Detected one that will work :) ");
                    kbdDevice = detectedKbd;
                }
                else Console.WriteLine("Detected one that won't work :( ");

            }
            //kbdDevice = HidDevices.Enumerate(VendorId, ProductId).LastOrDefault();
            if (kbdDevice == null)
                return;
            dispatcherTimer.Stop();
            SetTitle(true, "Connected");
            kbdDevice.Inserted += KbdDevice_Inserted;
            kbdDevice.Removed += KbdDevice_Removed;
            kbdDevice.MonitorDeviceEvents = true;
        }`

This modification in a non working condition will make the keyboard work and display this at the output:
`
Detected one Keyboard connected!
Detected: VendorID=0x0483, ProductID=0x573E, Version=512, DevicePath=\\?\hid#vid_0483&pid_573e&mi_01#a&177847e2&0&0000#{4d1e55b2-f16f-11cf-88cb-001111000030}
Description: Dispositivo compatible con HID
DevicePath: \\?\hid#vid_0483&pid_573e&mi_01#a&177847e2&0&0000#{4d1e55b2-f16f-11cf-88cb-001111000030}
Attributes: HidLibrary.HidDeviceAttributes
Capabilites: HidLibrary.HidDeviceCapabilities
Detected one that will work :)

Detected one Keyboard connected!
Detected: VendorID=0x0483, ProductID=0x573E, Version=512, DevicePath=\\?\hid#vid_0483&pid_573e&mi_00#a&4482ba4&0&0000#{4d1e55b2-f16f-11cf-88cb-001111000030}\kbd
Description: Dispositivo de teclado HID
DevicePath: \\?\hid#vid_0483&pid_573e&mi_00#a&4482ba4&0&0000#{4d1e55b2-f16f-11cf-88cb-001111000030}\kbd
Attributes: HidLibrary.HidDeviceAttributes
Capabilites: HidLibrary.HidDeviceCapabilities
Detected one that won't work :(
`

The only difference that the HIDLibrary is showing as far as I know is the ending \kbd of one of them on the DevicePath.
What the modification is doing to make the program select the right one is:
- Checking every entry listed by the search function of the Enumerate method.
- Checking for each entry that the device is listed as connected
- Checking that entry doesn't end with kbd. Because that's the device that won't work.

### Final notes
I have the feeling that this fix is kind of ugly. Excluding a device by it's ending on the device path probably doesn't cut it.
And i'm unsure about the longevity of the fix on future Windows releases.

I don't know if anyone knows a better solution, to differentiate between the good and bad HID device now that we have the problem identified.

If you want to have this solution implemented for the time being, I can clean up the logging output lines and commit a pull request.

shaise, 2023-02-10:
I just can't reproduce this issue on my PC. No matter what usb port I use, it always recognize the device.
Can you advise how to reproduce this issue?
What windows version do you use?

CJGuirao, 2023-02-11:
I'm using Windows 11

Using devmanview64 I can see the two installed devices (look for the device with VID 0483 PID 573e) :

```
HID Keyboard Device	(Standard keyboards)	kbdhid	Keyboard		HID\VID_0483&PID_573E&MI_00\a&4482ba4&0&0000		0x000000a0	0x00000000	No	No	07/02/2023 4:15:39	07/02/2023 4:15:39		{7fa5de54-2ab7-5446-97a0-875568c42bd5}	{4d36e96b-e325-11ce-bfc1-08002be10318}	07/02/2023 4:15:39	07/02/2023 4:15:39	10/02/2023 4:17:55	10/02/2023 9:45:07	HID Keyboard Device	10.0.22621.1	keyboard.inf	HID_Keyboard_Inst.NT	21/06/2006	07/02/2023 4:15:39

HID-compliant device	(Standard system devices)		HIDClass		HID\VID_0483&PID_573E&MI_01\a&177847e2&0&0000		0x000000e0	0x00000000	No	No	07/02/2023 4:15:39	07/02/2023 4:15:39		{7fa5de54-2ab7-5446-97a0-875568c42bd5}	{745a17a0-74d3-11d0-b6fe-00a0c90f57da}	07/02/2023 4:15:39	07/02/2023 4:15:39	10/02/2023 4:17:55	10/02/2023 9:45:07	HID-compliant device	10.0.22621.819	input.inf	HID_Raw_Inst.NT	21/06/2006	07/02/2023 4:15:39
```

I had the issue twice , just by plugging the device while testing it. I used different ports on different hubs and it happened.

To force this issue It may work to unplug the device, uninstall the entry that is detected as a keyboard with devmanview and plug it again so windows reinstall the device driver.

That may switch the order of the devices.

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

shaise, 2023-02-11:
Do you have an access to a windows 10 machine, to see if you have the same problem?

CJGuirao, 2023-02-12:
No right now,
I'll find one to test it.

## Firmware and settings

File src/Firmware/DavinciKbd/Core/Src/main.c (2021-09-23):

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
/* Includes ------------------------------------------------------------------*/
#include "main.h"
#include "usb_device.h"

/* USER CODE BEGIN Includes */
#include "kbd_led.h"
#include "usbd_customhid.h"
#include "settings.h"
/* USER CODE END Includes */

TIM_HandleTypeDef htim1;
TIM_HandleTypeDef htim2;

/* USER CODE BEGIN PV */
extern USBD_HandleTypeDef hUsbDeviceFS;
uint8_t reprep[10] = {1,2,3,4,5,6};

/* USER CODE END PV */

void SystemClock_Config(void);
static void MX_GPIO_Init(void);
static void MX_TIM1_Init(void);
static void MX_TIM2_Init(void);
/**
  * @brief  The application entry point.
  * @retval int
  */
int main(void)
{
  /* MCU Configuration--------------------------------------------------------*/

  /* Reset of all peripherals, Initializes the Flash interface and the Systick. */
  HAL_Init();

  /* Configure the system clock */
  SystemClock_Config();

  /* Initialize all configured peripherals */
  MX_GPIO_Init();
  MX_TIM1_Init();
  MX_USB_DEVICE_Init();
  MX_TIM2_Init();
  /* USER CODE BEGIN 2 */
  InitSettings();
  KbdInit();

  /* USER CODE END 2 */

  /* Infinite loop */
  /* USER CODE BEGIN WHILE */
  while (1)
  {
	  //HAL_Delay(1000);
	  //USBD_CUSTOM_HID_SendReport(&hUsbDeviceFS, reprep, 10);
	  PollKbdJog();
    /* USER CODE END WHILE */

    /* USER CODE BEGIN 3 */
  }
  /* USER CODE END 3 */
}

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


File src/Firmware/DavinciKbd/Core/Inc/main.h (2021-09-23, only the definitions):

#define KbdI0_Pin GPIO_PIN_0
#define KbdI0_GPIO_Port GPIOA
#define KbdI1_Pin GPIO_PIN_1
#define KbdI1_GPIO_Port GPIOA
#define KbdI2_Pin GPIO_PIN_2
#define KbdI2_GPIO_Port GPIOA
#define KbdI3_Pin GPIO_PIN_3
#define KbdI3_GPIO_Port GPIOA
#define KbdI4_Pin GPIO_PIN_4
#define KbdI4_GPIO_Port GPIOA
#define KbdI5_Pin GPIO_PIN_5
#define KbdI5_GPIO_Port GPIOA
#define KbdI6_Pin GPIO_PIN_6
#define KbdI6_GPIO_Port GPIOA
#define KbdL0_Pin GPIO_PIN_0
#define KbdL0_GPIO_Port GPIOB
#define KbdL1_Pin GPIO_PIN_10
#define KbdL1_GPIO_Port GPIOB
#define KbdL2_Pin GPIO_PIN_11
#define KbdL2_GPIO_Port GPIOB
#define KbdL3_Pin GPIO_PIN_12
#define KbdL3_GPIO_Port GPIOB
#define KbdL4_Pin GPIO_PIN_13
#define KbdL4_GPIO_Port GPIOB
#define KbdL5_Pin GPIO_PIN_14
#define KbdL5_GPIO_Port GPIOB
#define KbdL6_Pin GPIO_PIN_15
#define KbdL6_GPIO_Port GPIOB
#define EncoderA_Pin GPIO_PIN_8
#define EncoderA_GPIO_Port GPIOA
#define EncoderB_Pin GPIO_PIN_9
#define EncoderB_GPIO_Port GPIOA
#define KbdO0_Pin GPIO_PIN_3
#define KbdO0_GPIO_Port GPIOB
#define KbdO1_Pin GPIO_PIN_4
#define KbdO1_GPIO_Port GPIOB
#define KbdO2_Pin GPIO_PIN_5
#define KbdO2_GPIO_Port GPIOB
#define KbdO3_Pin GPIO_PIN_6
#define KbdO3_GPIO_Port GPIOB
#define KbdO4_Pin GPIO_PIN_7
#define KbdO4_GPIO_Port GPIOB
#define KbdO5_Pin GPIO_PIN_8
#define KbdO5_GPIO_Port GPIOB
#define KbdO6_Pin GPIO_PIN_9
#define KbdO6_GPIO_Port GPIOB

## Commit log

2021-09-26 add mechanics
    [DaVinciKbdBot.stl, DavinciKbdTop.stl, KbdEncoderBase.stl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]
2022-09-24 v1.1 gerbers
    [DaVinciKbd.kicad_pcb]
2023-02-02 fix missing button
2023-02-08 Added polarities on PCB and component values on both sch&PCB
    Updated the values of all the components in schematics and PCB.
    Modified silkscreen to print diode polarity, and resistor values
    [DaVinciKbd-B_Cu.gbl, DaVinciKbd-B_Mask.gbs, DaVinciKbd-B_Silkscreen.gbo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]
2023-02-08 Modified Readme File with all the information regading BOM

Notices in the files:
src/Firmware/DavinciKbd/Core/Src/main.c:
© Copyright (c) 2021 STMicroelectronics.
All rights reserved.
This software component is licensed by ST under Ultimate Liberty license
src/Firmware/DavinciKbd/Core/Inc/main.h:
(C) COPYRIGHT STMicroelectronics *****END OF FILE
